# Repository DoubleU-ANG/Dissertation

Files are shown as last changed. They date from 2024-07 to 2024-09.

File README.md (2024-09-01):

# Dissertation: Connected Seat System
## Introduction: 
Smart Connected Seats serve as a helpful guide in public places like libraries and teaching theatres, assisting people in finding available and suitable seating. The Smart Connected Seats system combines a sensor-enabled chair and data communication centre. Every chair includes a millimetre-wave radar, to detect if someone is sitting down, along with sensors for carbon dioxide, temperature, humidity and light, to monitor the surrounding environment to ensure comfort. The communication centre visualises the data from the sensors. It includes model of the chairs, which rise when someone sits on real chairs, and an e-ink display to communicate the environmental conditions. 

## Hypothesis: 
How can a smart connected seat system using millimeter-wave radar and various environmental sensors help people to find a seat with better learning or working experience.

## Aims:
This project aims to implementing a smart Internet of Things (IoT) strategy on chairs, in order to transform the way we interact with these spaces

## Methodologies:
The Smart Connected System includes smart chair detector equipped with few sensors and physical twins of chair.

Project Overview:

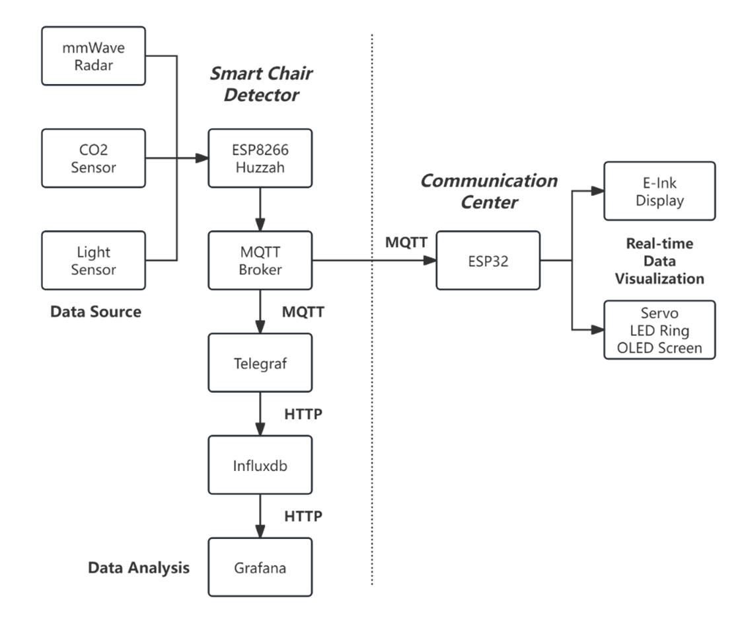
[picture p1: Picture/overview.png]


### Hardware:

#### Hardware List:

##### 1. Microcontrollers:
ESP8266 HUZZAH (Smart Chair Detector)
ESP32 E-paper screen driver board (Communication Center)

##### 2. Sensors:
This project use mm-Wave radar SEN0395, CO2, temperature and humidity sensor SCD30, and light sensor TCS3472. Use the code provided to test each sensor before integration.

SEN0395:

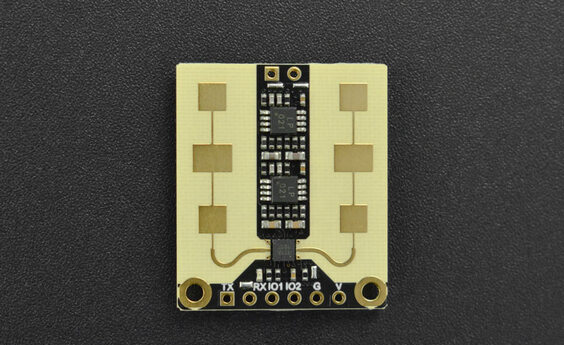
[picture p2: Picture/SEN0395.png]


SCD30:

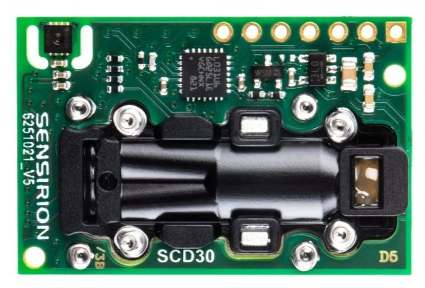
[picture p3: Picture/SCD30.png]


TCS3472:

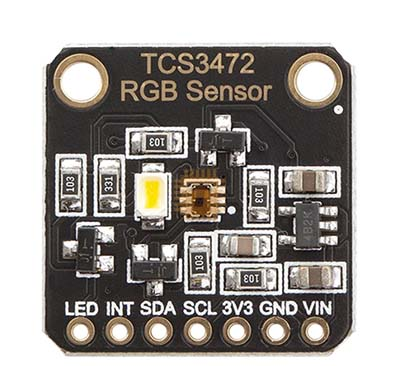
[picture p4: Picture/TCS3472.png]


##### 3. Actuators:
Actuators are mainly used in communication center, they are: servos, LED rings and OLED screens.

#### Circuit:
##### Circuit Connection:
Connect all the sensor as the schematic shown as below:

Smart chair detector circuit schematic:

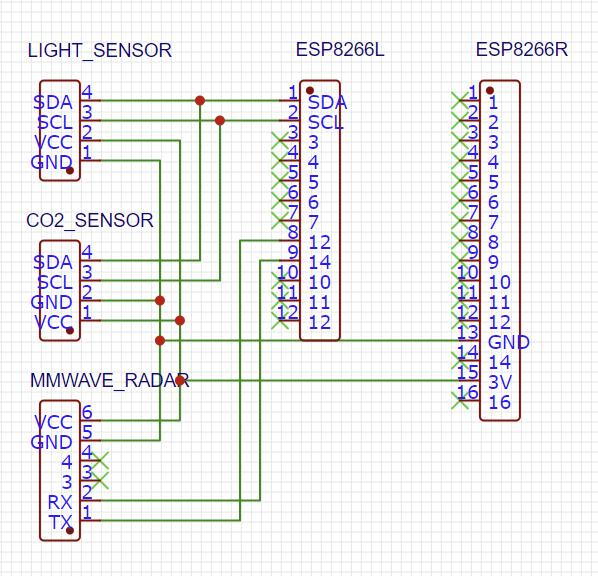
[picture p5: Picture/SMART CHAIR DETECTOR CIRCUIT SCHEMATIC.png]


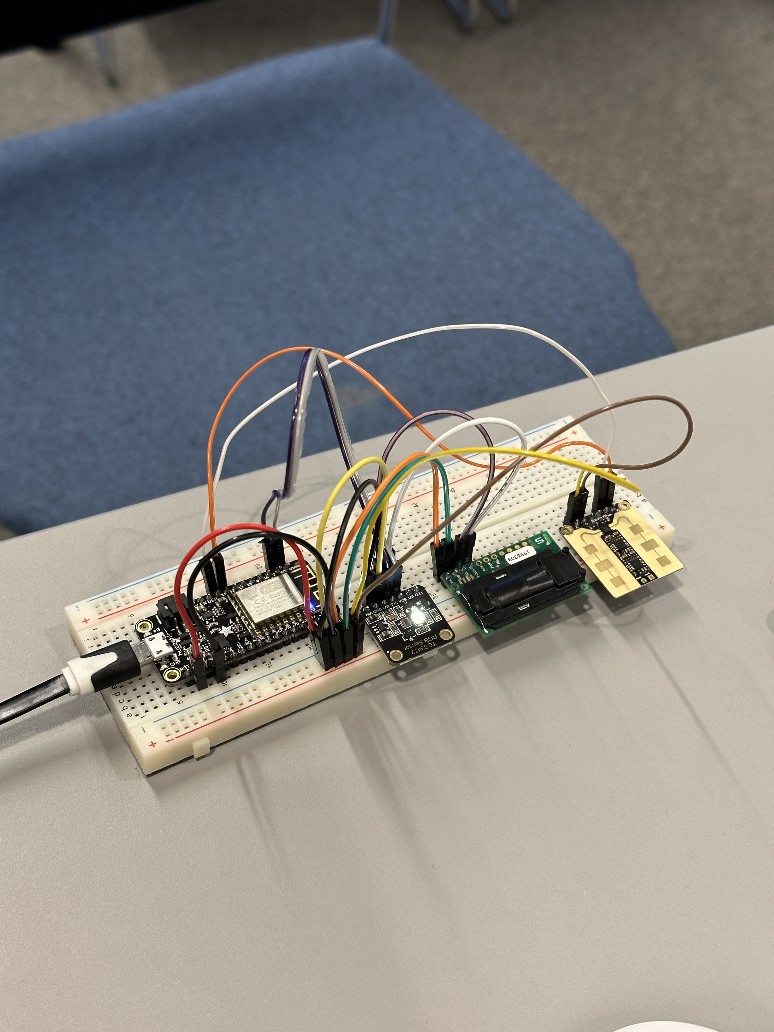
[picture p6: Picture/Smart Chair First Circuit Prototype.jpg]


Communication center circuit schematic:

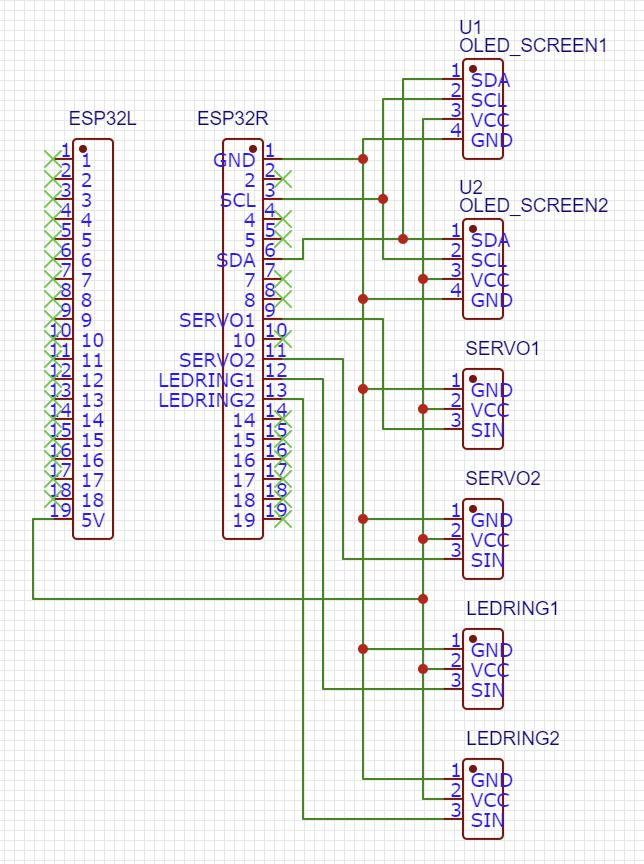
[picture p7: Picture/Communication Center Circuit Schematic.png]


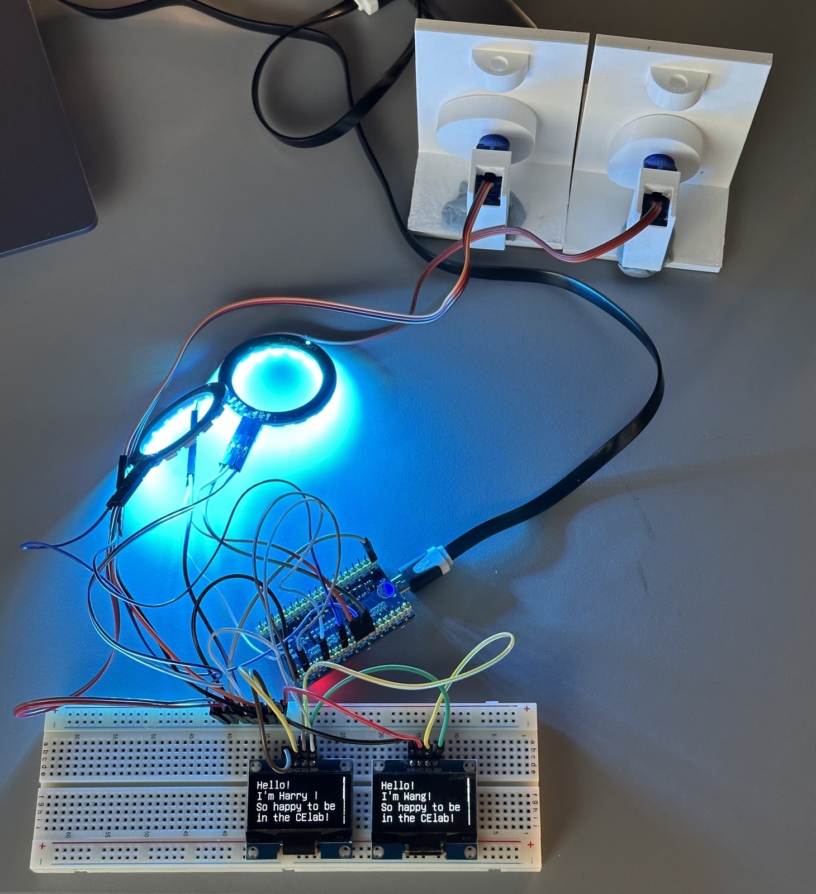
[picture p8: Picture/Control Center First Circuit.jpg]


It worth noting that when connect two OLED screens to circuit, physical address of one of them should be changed by soldering the resister behind the screen (shown as picture below) to another position for another address, otherwise the microcontroller is not able to recognise these two screens. It has two physical address； 0x78 and 0x7A，and 0x78 is the default one.

0x78；

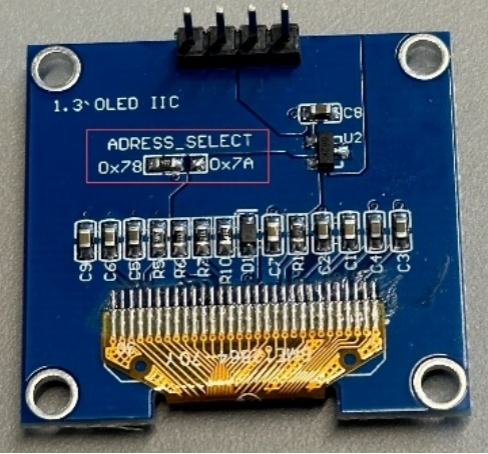
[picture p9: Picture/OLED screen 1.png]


0x7A:(manually modification needed)

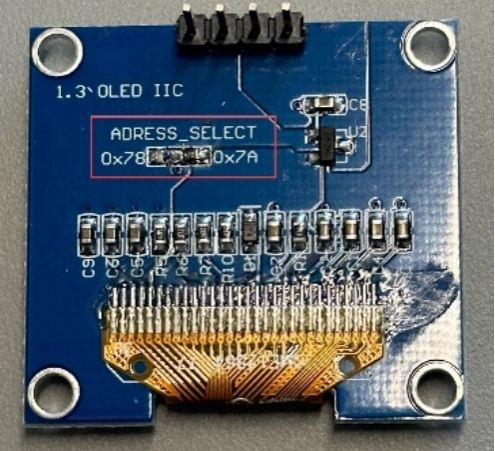
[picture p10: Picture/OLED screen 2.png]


After successfully assembling the circuit board and connecting all components, test the circuit functions in Arduino IDE by uploding the code provided to the microcontroller.

Code for smart chair detector:

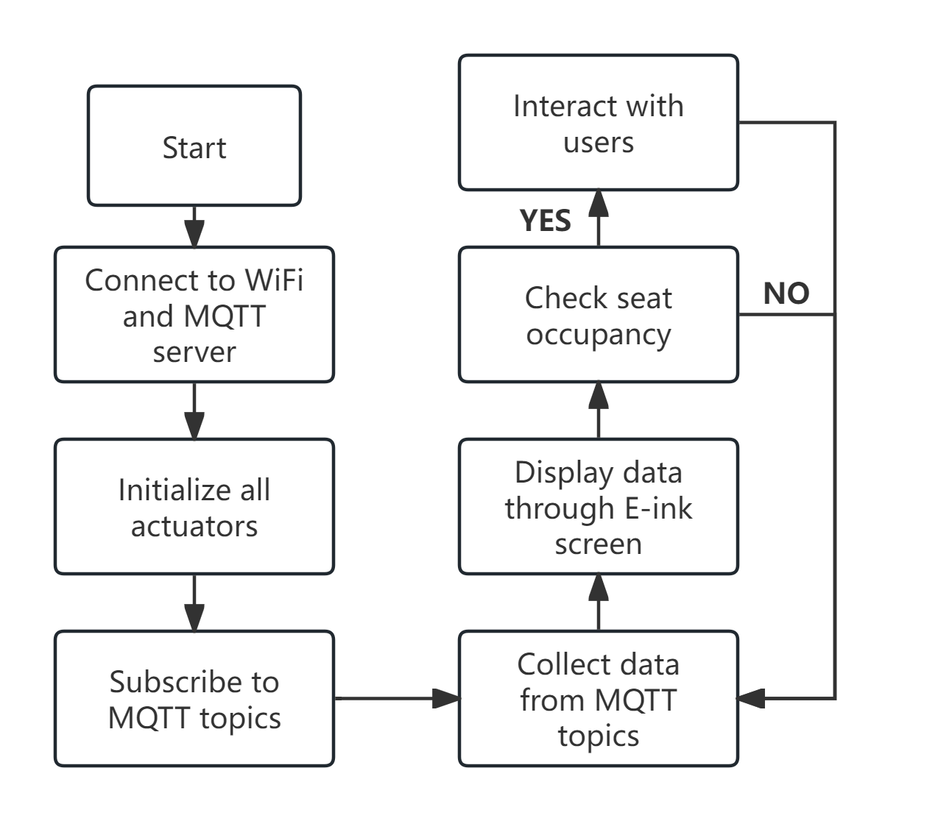
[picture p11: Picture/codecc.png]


Code for communication center:

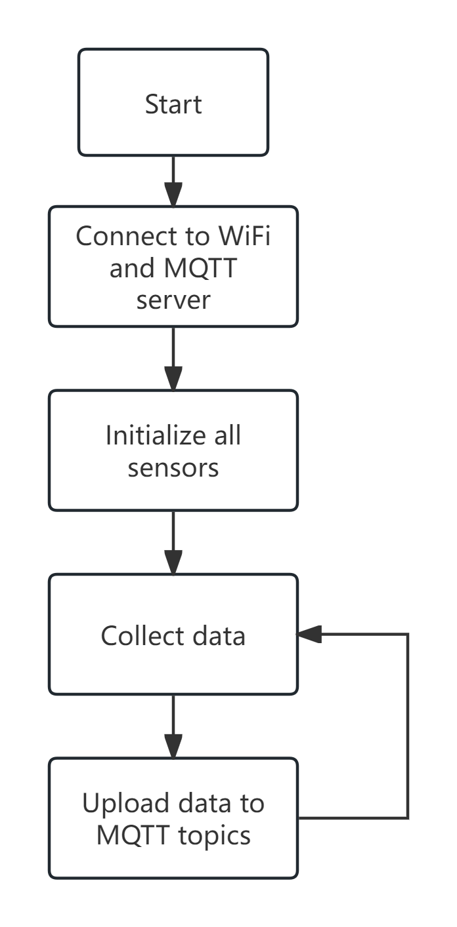
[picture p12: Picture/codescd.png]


##### Printed Circuit Board (PCB)
PCB has been designed for ensuring a more stable and wireless circuit. You can build your own PCB or modified mine which I designed on LCEDA according to your project.

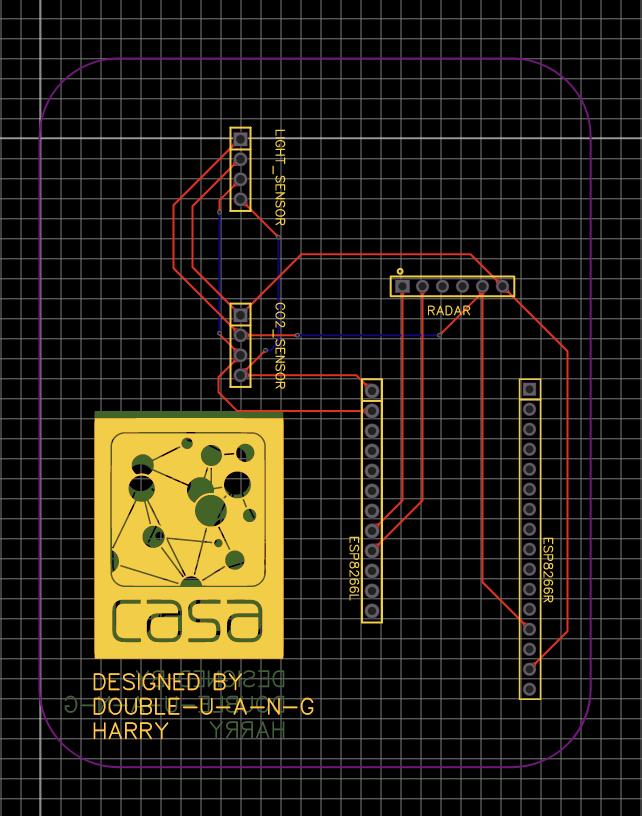
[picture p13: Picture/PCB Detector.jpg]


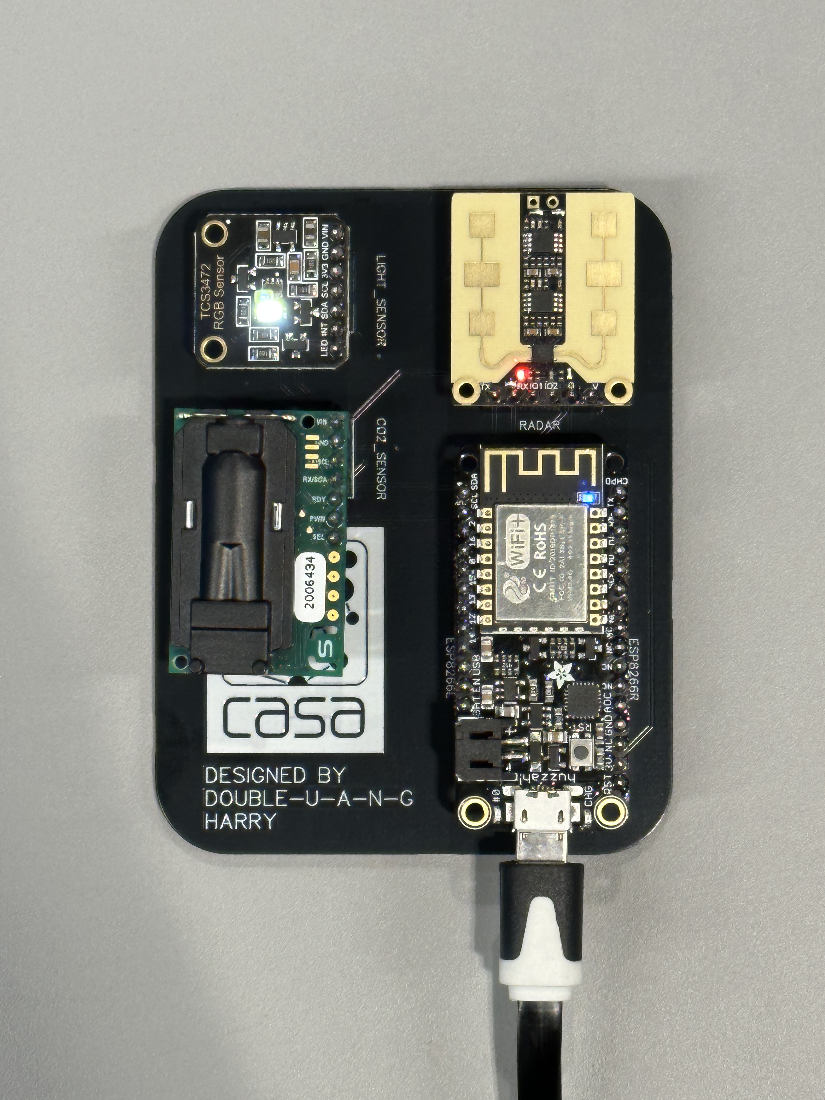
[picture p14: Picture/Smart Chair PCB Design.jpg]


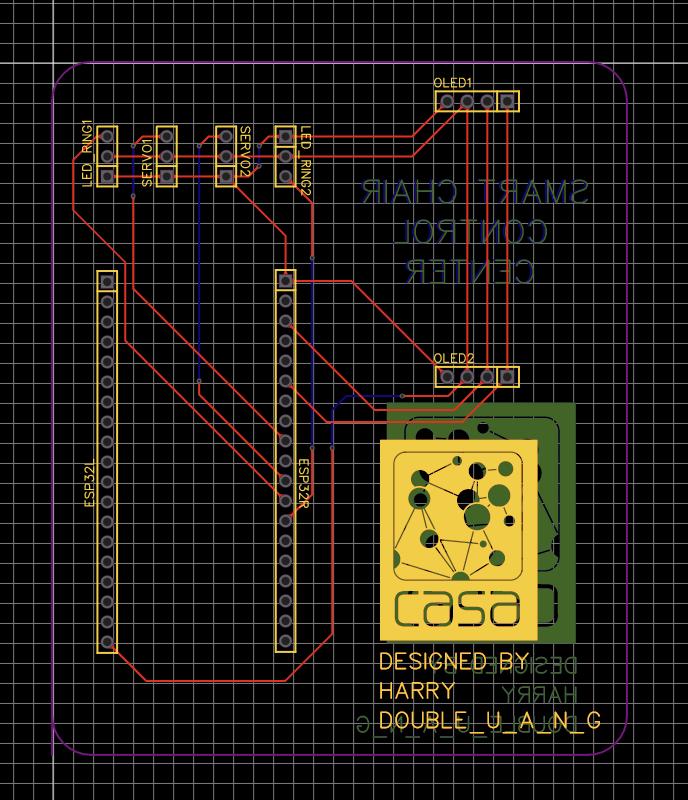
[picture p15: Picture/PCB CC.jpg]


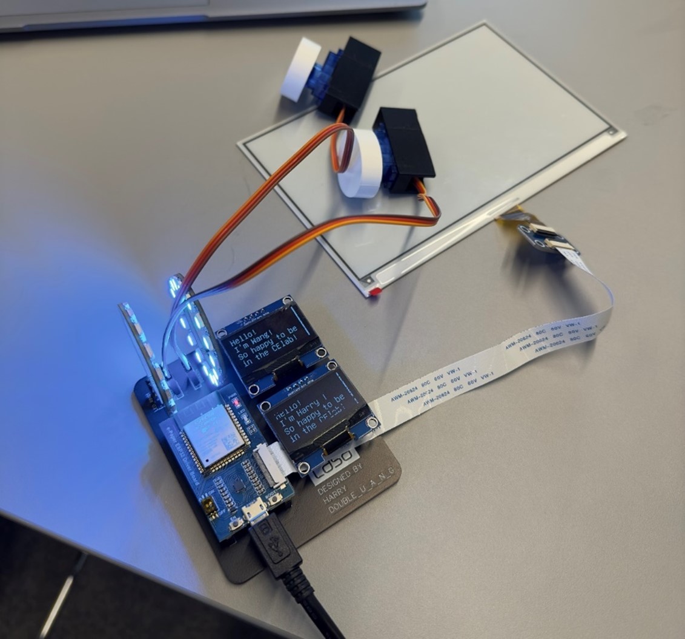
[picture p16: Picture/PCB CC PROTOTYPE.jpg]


#### Enclosure：
Custom-designed enclosures were developed for the circuit boards, sensors and actuators to facilitate their deployment in targeted scenarios. You can build your own enclosure or modified mine on Fusion 360 according to your project.

Smart Chair Detector Enclosure:

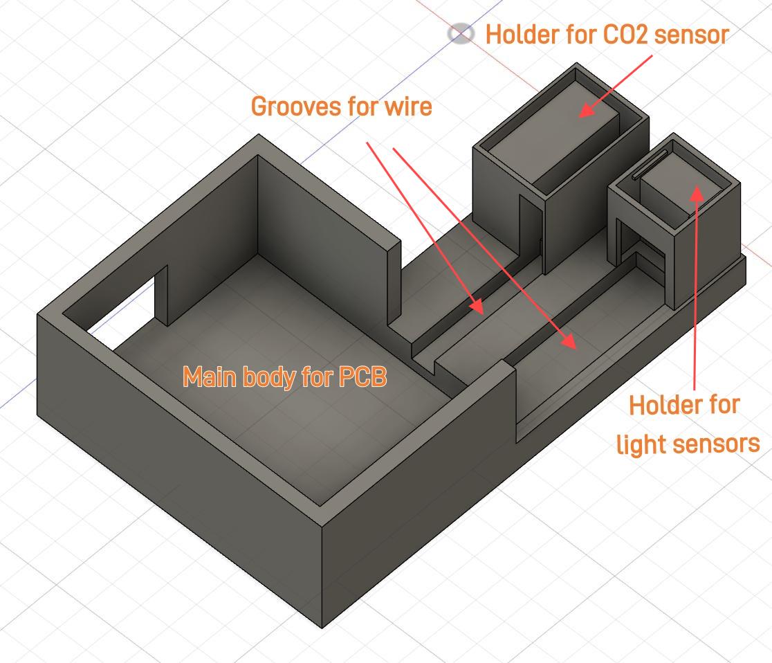
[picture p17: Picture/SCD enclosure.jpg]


Base of Communication Center:

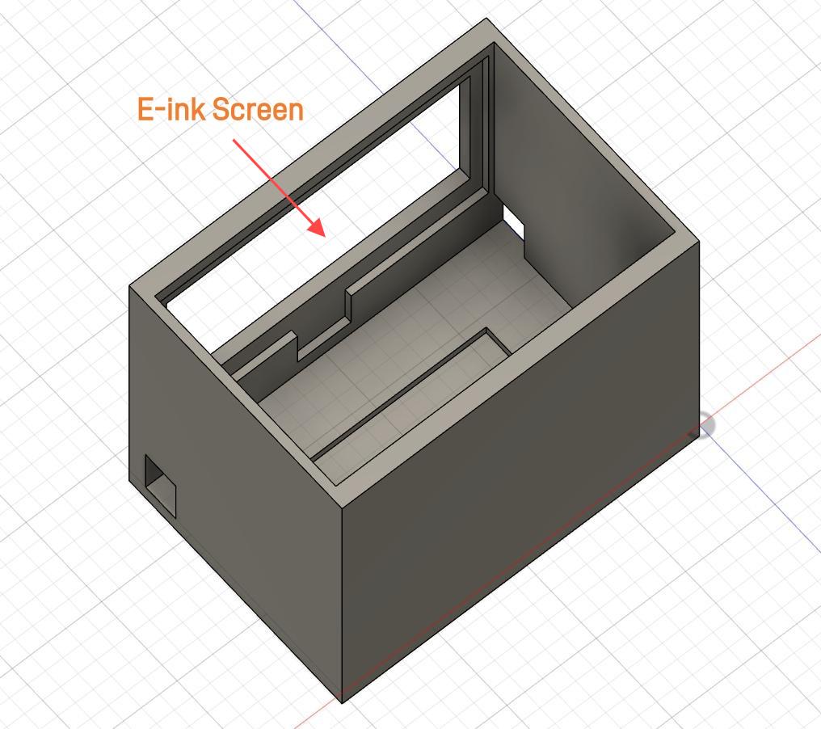
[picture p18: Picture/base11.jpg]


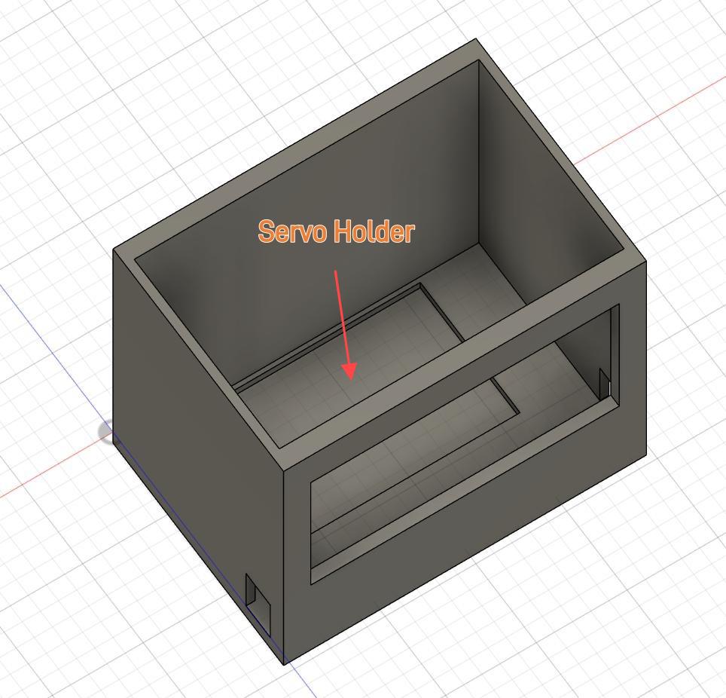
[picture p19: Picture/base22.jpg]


Servo Holder:

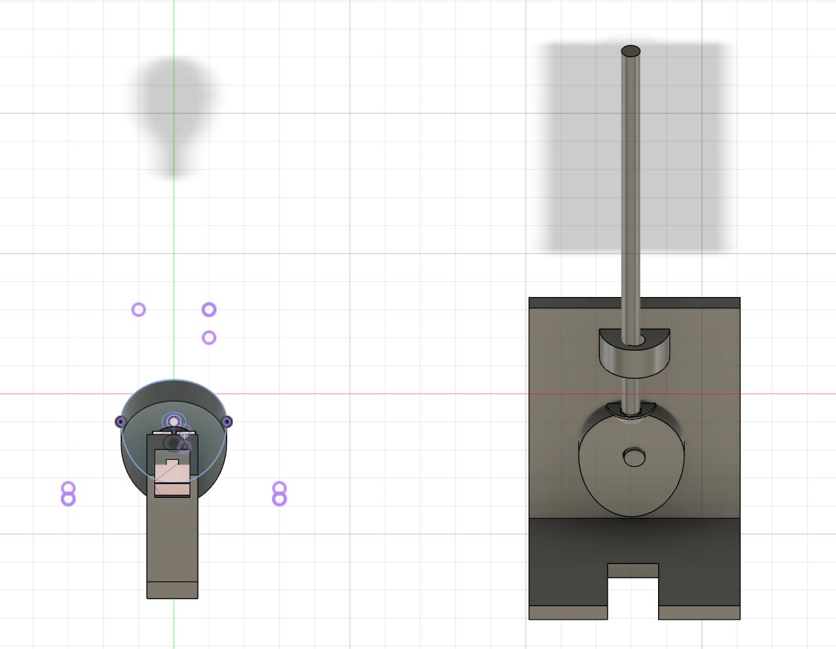
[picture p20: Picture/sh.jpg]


Top of Communication Center

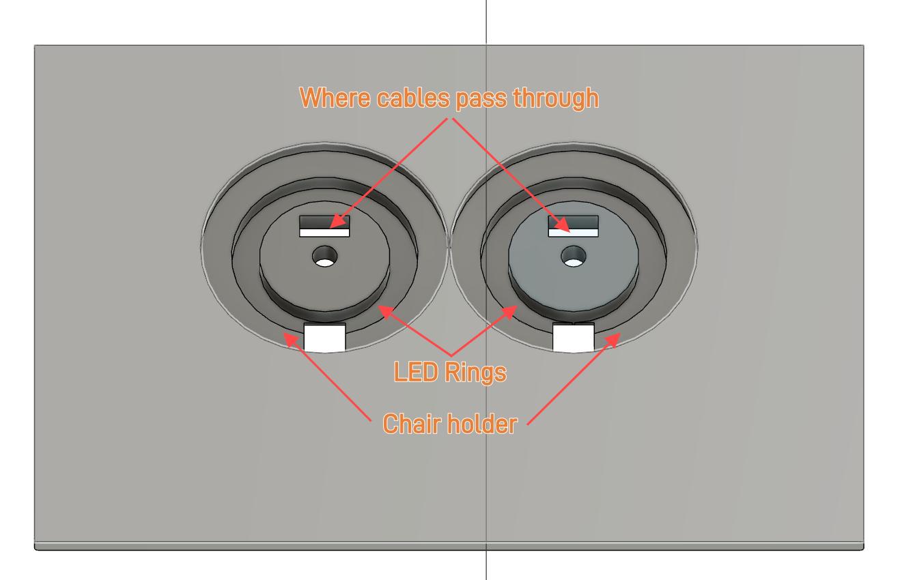
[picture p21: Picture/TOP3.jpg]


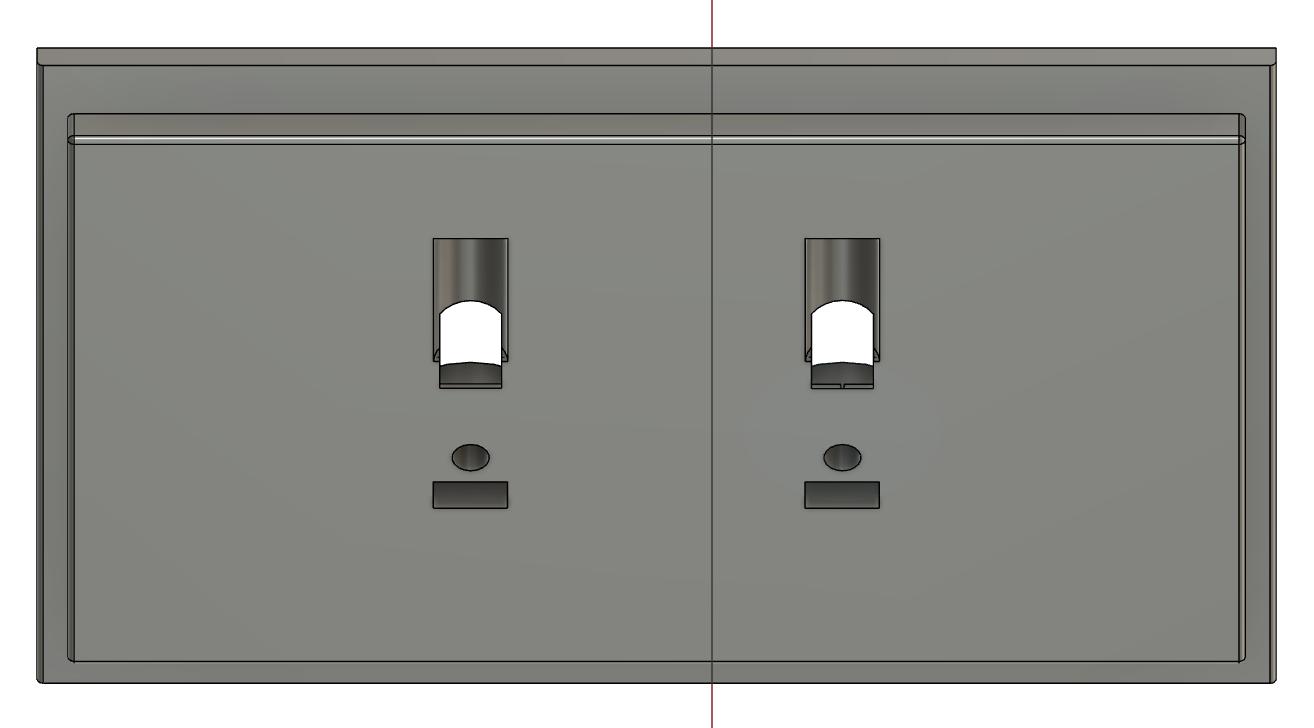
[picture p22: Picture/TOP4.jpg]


Chair Holder:

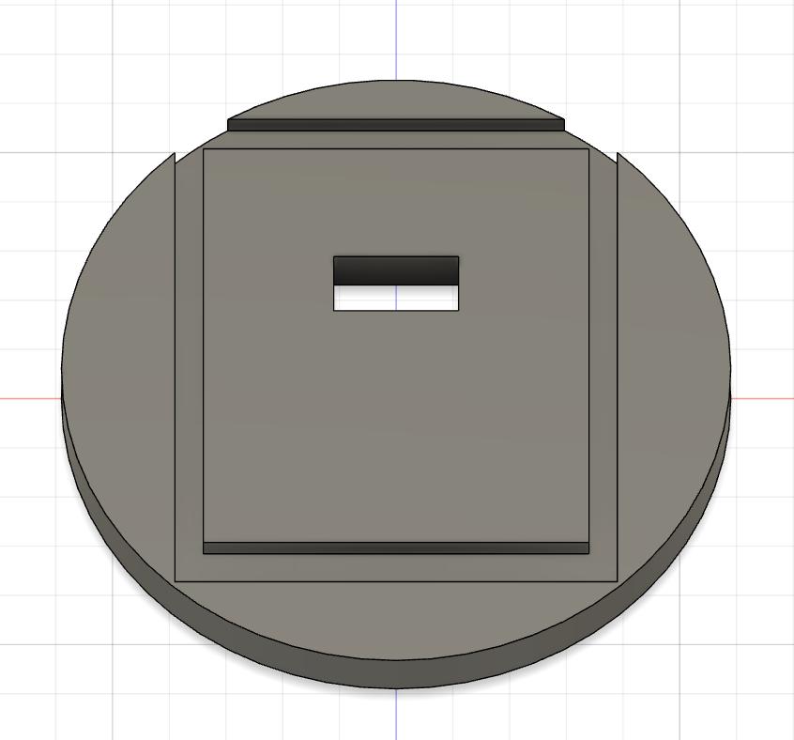
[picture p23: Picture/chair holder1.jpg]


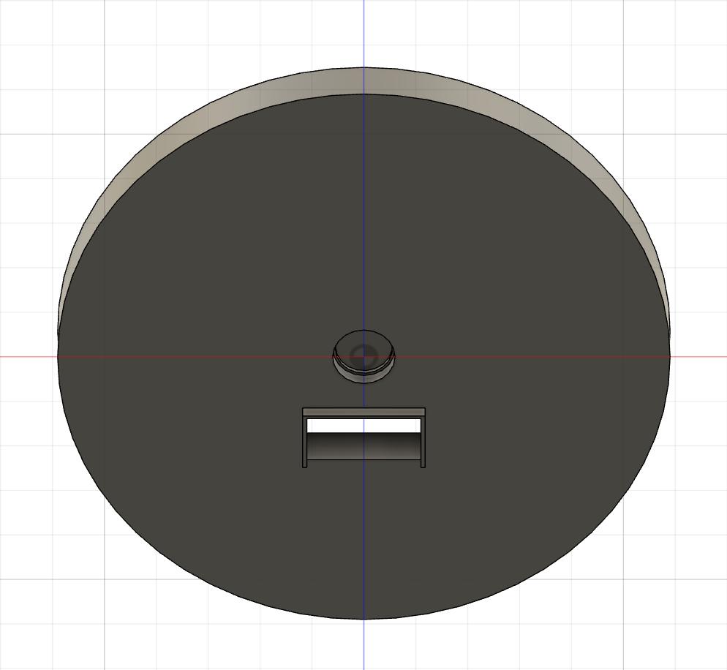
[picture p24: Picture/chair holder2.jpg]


Chair:

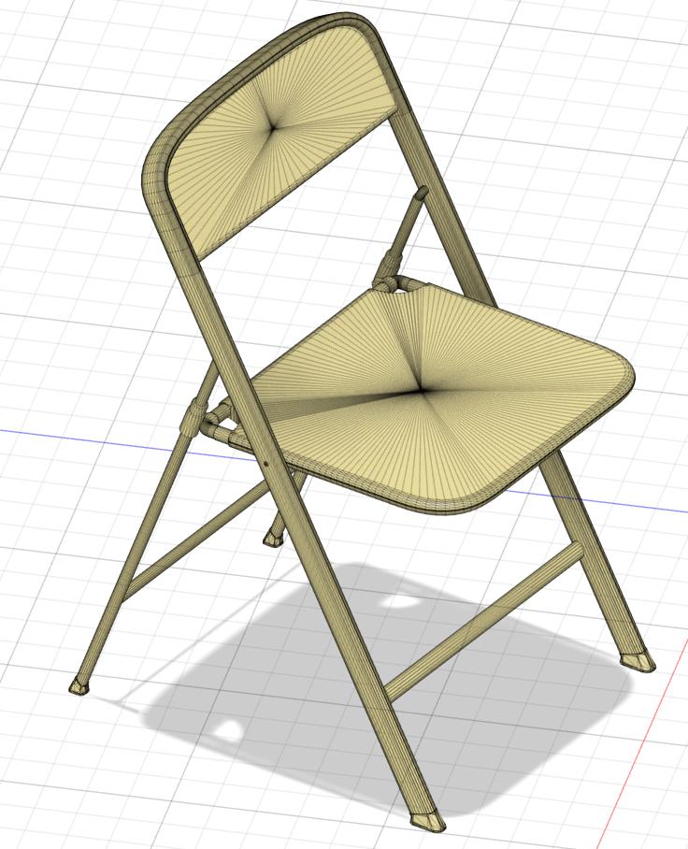
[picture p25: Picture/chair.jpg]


## Result:

Smart Chair Detector:

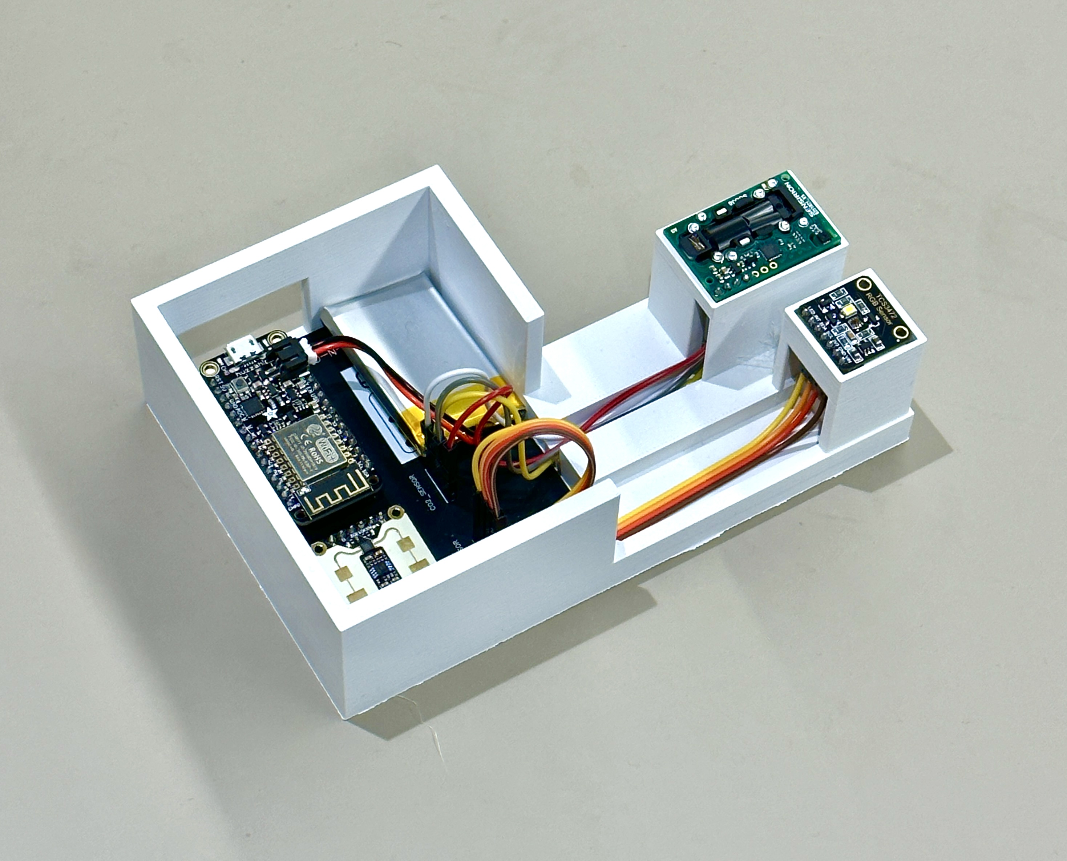
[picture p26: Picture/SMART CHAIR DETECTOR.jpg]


Deployment:

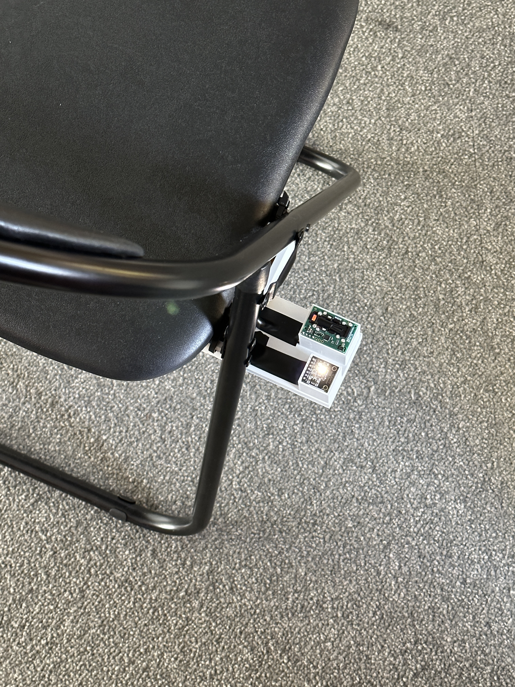
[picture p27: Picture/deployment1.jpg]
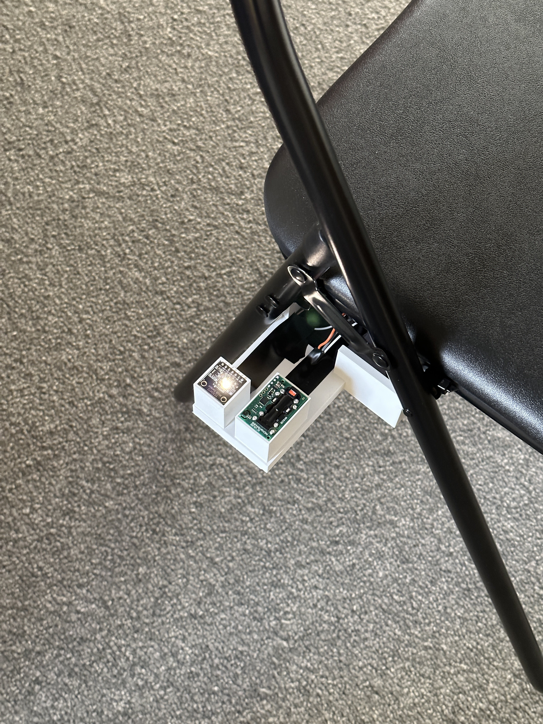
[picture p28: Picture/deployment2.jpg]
 

Communication Center:

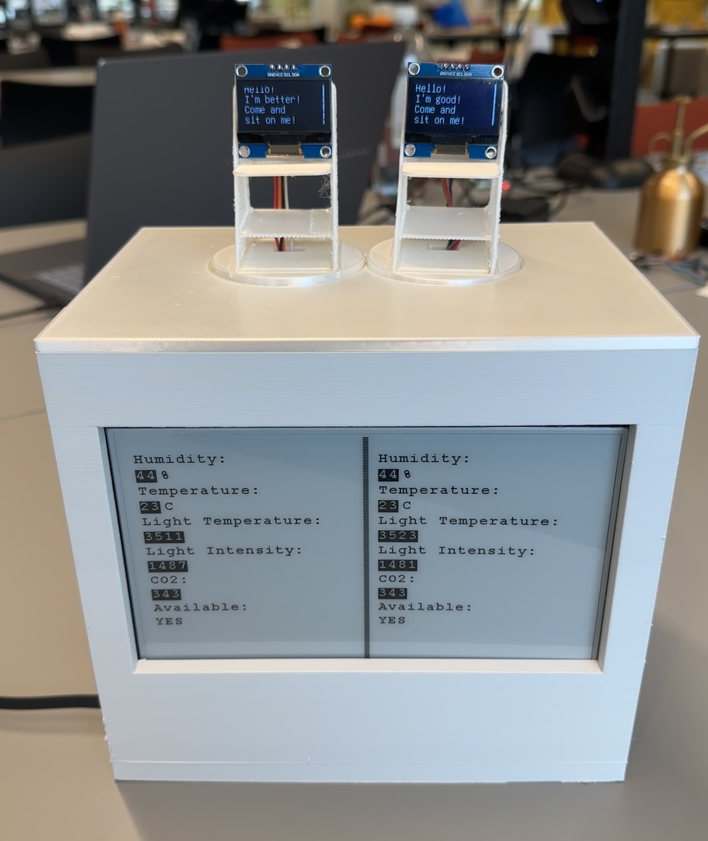
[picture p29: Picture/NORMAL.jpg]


When people sit on one of the chair:

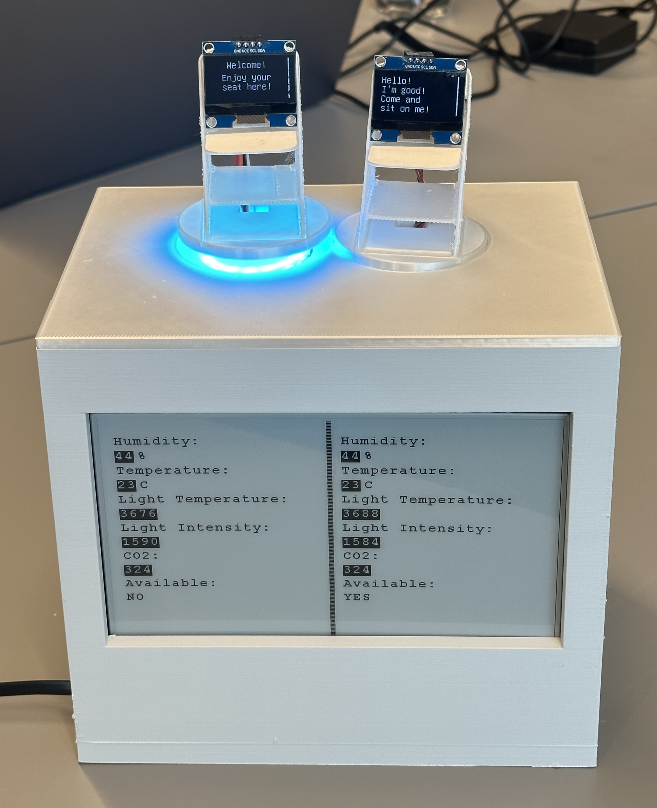
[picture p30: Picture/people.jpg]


## Steps for recreation:

1. Prepare the hardware needed.

2. Connect all the components and test the functions by code. Remember to replace the key information for WiFi and MQTT broker with your own one.

3. Design your PCB (optional) and Enclosure or modified mine according to your own requirement.

4. Assemble all the electronic components and enclosure.

5. Run the code and deploy on your chair

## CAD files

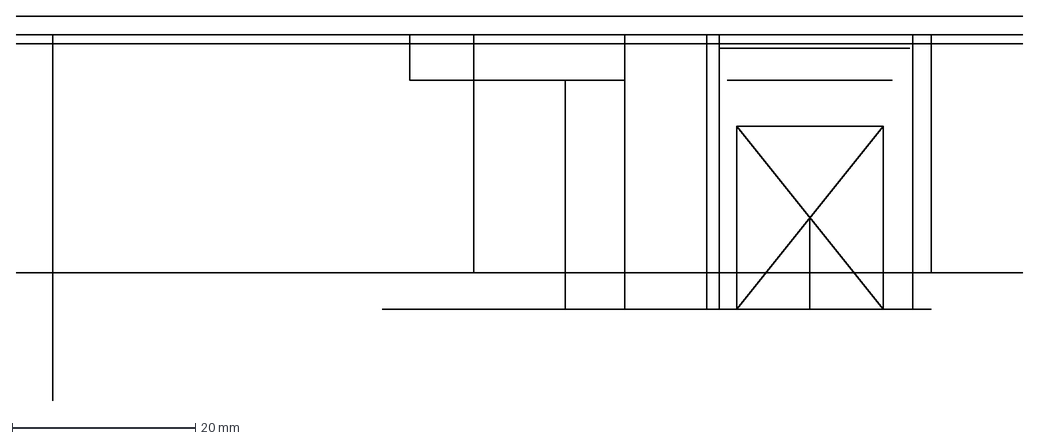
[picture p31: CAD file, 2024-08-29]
3D model/Smart Chair.dxf
110.0 x 42.0 mm

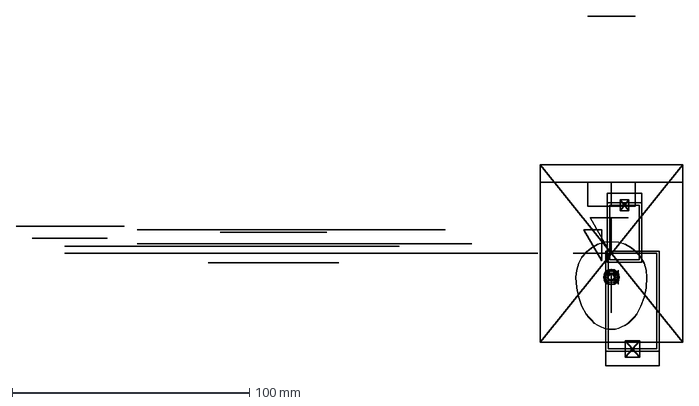
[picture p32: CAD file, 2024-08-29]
3D model/Control Center.dxf
281.0 x 147.3 mm

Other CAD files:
3D model/CHair.dxf

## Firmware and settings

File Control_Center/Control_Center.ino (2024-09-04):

#include "DEV_Config.h"
#include "EPD.h"
#include "GUI_Paint.h"
#include <PubSubClient.h>
#include <stdlib.h>
#include <WiFi.h>
#include <ezTime.h>
#include "SPIFFS.h"
#include <WiFi.h>
#include <HTTPClient.h>
#include <ArduinoJson.h>
#include <Adafruit_NeoPixel.h>
#include <ESP32Servo.h>
#include <Arduino.h>
#include <U8g2lib.h>
#include <Wire.h>
#ifdef __AVR__
#include <avr/power.h> // Required for 16 MHz Adafruit Trinket
#endif

#define PIN0 4 // On Trinket or Gemma, suggest changing this to 1
#define PIN1 16
// How many NeoPixels are attached to the Arduino?
#define NUMPIXELS 16 // Popular NeoPixel ring size
#define OLED_ADDR_1 0x3C
#define OLED_ADDR_2 0x3D
#define DELAYVAL 500 // Time (in milliseconds) to pause between pixels
// When setting up the NeoPixel library, we tell it how many pixels,
// and which pin to use to send signals. Note that for older NeoPixel
// strips you might need to change the third parameter -- see the
// strandtest example for more information on possible values.
Adafruit_NeoPixel pixels(NUMPIXELS, PIN0, NEO_GRB + NEO_KHZ800);
Adafruit_NeoPixel pixels1(NUMPIXELS, PIN1, NEO_GRB + NEO_KHZ800);
U8G2_SSD1306_128X64_NONAME_F_HW_I2C u8g2(U8G2_R0, /* reset=*/U8X8_PIN_NONE, /* clock=*/22, /* data=*/21);
U8G2_SSD1306_128X64_NONAME_F_HW_I2C u8g21(U8G2_R0, /* reset=*/U8X8_PIN_NONE, /* clock=*/22, /* data=*/21);
Servo myservo;
Servo myservo1;
int pos = 0;
int servoPin=18;
int servoPin1=17;

int light_temperature1 = 0;
int temperature1 = 0;
int humidity1 = 0;
int people1 = 0;
int light_intensity1 = 0;
int CO21 = 0;

int light_temperature2 = 0;
int temperature2 = 0;
int humidity2 = 0;
int people2 = 0;
int light_intensity2 = 0;
int CO22 = 0;

#define SECRET_SSID "use your own here"
#define SECRET_PASS "use your own here"
#define SECRET_MQTTUSER "use your own here"
#define SECRET_MQTTPASS "use your own here"

const char* ssid     = SECRET_SSID;
const char* password = SECRET_PASS;
const char* mqttuser = SECRET_MQTTUSER;
const char* mqttpass = SECRET_MQTTPASS;

const char* mqtt_server = "mqtt.cetools.org";
WiFiClient espClient;
PubSubClient client(espClient);
long lastMsg = 0;
char msg[50];
int value = 0;

UBYTE *BlackImage;
UWORD Imagesize = ((EPD_7IN5_V2_WIDTH % 8 == 0) ? (EPD_7IN5_V2_WIDTH / 8 ) : (EPD_7IN5_V2_WIDTH / 8 + 1)) * EPD_7IN5_V2_HEIGHT;

PAINT_TIME sys_time;
UWORD width = EPD_7IN5_V2_WIDTH;
UWORD height = EPD_7IN5_V2_HEIGHT;

UWORD line1_y = height / 3;
UWORD line2_y = height * 2 / 3;
UWORD line3_y = width / 2;

unsigned long lastUpdate = 0;  
const unsigned long updateInterval = 10000; 


void moveServoTo180(Servo &servo) {
  for (int pos = 0; pos <= 180; pos += 1) { 
    servo.write(pos);
    delay(20);
  }
}

// Function to move myservo from 180 to 0 degrees
void moveServoTo0(Servo &servo) {
  for (int pos = 180; pos >= 0; pos -= 1) {
    servo.write(pos);
    delay(20);
  }
}

void sentence01()
{
    u8g2.setFont(u8g2_font_unifont_t_chinese2); // use chinese2
 u8g2.firstPage();
 do
 {
  u8g2.setCursor(5, 15);
  u8g2.print("Hello!");
  u8g2.setCursor(5, 30);
  u8g2.print("I'm better!"); 
  u8g2.setCursor(5, 45);
  u8g2.print("Come and"); 
  u8g2.setCursor(5, 60); 
  u8g2.print("sit on me!"); 
 } while (u8g2.nextPage()); 
}

void sentence11()
{
   u8g21.setFont(u8g2_font_unifont_t_chinese2); // use chinese2
 u8g21.firstPage();
 do
 {
  u8g21.setCursor(5, 15);
  u8g21.print("Hello!");
  u8g21.setCursor(5, 30);
  u8g21.print("I'm good!"); 
  u8g21.setCursor(5, 45);
  u8g21.print("Come and"); 
  u8g21.setCursor(5, 60); 
  u8g21.print("sit on me!");
 } while (u8g21.nextPage()); 
}

void sentence02()
{
    u8g2.setFont(u8g2_font_unifont_t_chinese2); // use chinese2
 u8g2.firstPage();
 do
 {
  u8g2.setCursor(5, 15);
  u8g2.print("   Welcome!");
  u8g2.setCursor(5, 35);
  u8g2.print("  Enjoy your"); 
  u8g2.setCursor(5, 50);
  u8g2.print("  seat here!"); 
 // u8g2.setCursor(5, 60); 

 } while (u8g2.nextPage()); 
}

void sentence12()
{
   u8g21.setFont(u8g2_font_unifont_t_chinese2); // use chinese2
 u8g21.firstPage();
 do
 {
  u8g21.setCursor(5, 15);
  u8g21.print("Welcome!");
  u8g21.setCursor(5, 30);
  u8g21.print("Enjoy your"); 
  u8g21.setCursor(5, 45);
  u8g21.print("seat here!"); 
  u8g21.setCursor(5, 60); 
 
 } while (u8g21.nextPage()); 
}

void startWifi() {
  Serial.println();
  Serial.print("Connecting to ");
  Serial.println(ssid);
  WiFi.begin(ssid, password);

  while (WiFi.status() != WL_CONNECTED) {
    delay(500);
    Serial.print(".");
  }
  Serial.println("");
  Serial.println("WiFi connected");
  Serial.print("IP address: ");
  Serial.println(WiFi.localIP());
}

void sendMQTT() {
  if (!client.connected()) {
    reconnect();
  }
  client.loop();

  snprintf(msg, 50, "%.0i", t);
  Serial.print("Publish message for t: ");
  Serial.println(msg);
  client.publish("student/CASA0014/plant/ucfnaaf/rainrate1", msg);
}

void callback(char* topic, byte* payload, unsigned int length) {
  Serial.print("Message arrived [");
  Serial.print(topic);
  Serial.print("] ");

  char buffer[length + 1];
  for (int i = 0; i < length; i++) {
    buffer[i] = (char)payload[i];
    Serial.print(buffer[i]);
  }
  buffer[length] = '\0';
  Serial.println();

  if (strcmp(topic, "student/CASA0014/plant/ucfnaaf/Color Temperature1") == 0) {
    light_temperature = atoi(buffer);
    Serial.println("for the Color Temperature");
  } else if (strcmp(topic, "student/CASA0014/plant/ucfnaaf/Light Intensity1") == 0) {
    light_intensity = atoi(buffer);
    Serial.println("for the Light Intensity");
  } else if (strcmp(topic, "student/CASA0014/plant/ucfnaaf/Temperature1") == 0) {
    temperature = atoi(buffer);
    Serial.println("for the Temperature");
  } else if (strcmp(topic, "student/CASA0014/plant/ucfnaaf/Humidity1") == 0) {
    humidity = atoi(buffer);
    Serial.println("for the Humidity");
  } else if (strcmp(topic, "student/CASA0014/plant/ucfnaaf/CO21") == 0) {
    CO2 = atoi(buffer);
    Serial.println("for the CO2");
  } else if (strcmp(topic, "student/CASA0014/plant/ucfnaaf/People1") == 0) {
    people = atoi(buffer);
    Serial.println("for the People");
  }
    if (strcmp(topic, "student/CASA0014/plant/ucfnaaf/Color Temperature2") == 0) {
    light_temperature = atoi(buffer);
    Serial.println("for the Color Temperature");
  } else if (strcmp(topic, "student/CASA0014/plant/ucfnaaf/Light Intensity2") == 0) {
    light_intensity = atoi(buffer);
    Serial.println("for the Light Intensity");
  } else if (strcmp(topic, "student/CASA0014/plant/ucfnaaf/Temperature2") == 0) {
    temperature = atoi(buffer);
    Serial.println("for the Temperature");
  } else if (strcmp(topic, "student/CASA0014/plant/ucfnaaf/Humidity2") == 0) {
    humidity = atoi(buffer);
    Serial.println("for the Humidity");
  } else if (strcmp(topic, "student/CASA0014/plant/ucfnaaf/CO22") == 0) {
    CO2 = atoi(buffer);
    Serial.println("for the CO2");
  } else if (strcmp(topic, "student/CASA0014/plant/ucfnaaf/People2") == 0) {
    people = atoi(buffer);
    Serial.println("for the People");
  }
}

void reconnect() {
  while (!client.connected()) {
    Serial.print("Attempting MQTT connection...");
    String clientId = "ESP8266Client-";
    clientId += String(random(0xffff), HEX);
    
    if (client.connect(clientId.c_str(), mqttuser, mqttpass)) {
      Serial.println("connected");
      client.subscribe("student/CASA0014/plant/ucfnaaf/inTopic");
      client.subscribe("student/CASA0014/plant/ucfnaaf/Color Temperature1");
      client.subscribe("student/CASA0014/plant/ucfnaaf/Light Intensity1");
      client.subscribe("student/CASA0014/plant/ucfnaaf/Temperature1");
      client.subscribe("student/CASA0014/plant/ucfnaaf/Humidity1");
      client.subscribe("student/CASA0014/plant/ucfnaaf/CO21");
      client.subscribe("student/CASA0014/plant/ucfnaaf/Color Temperature2");
      client.subscribe("student/CASA0014/plant/ucfnaaf/Light Intensity2");
      client.subscribe("student/CASA0014/plant/ucfnaaf/Temperature2");
      client.subscribe("student/CASA0014/plant/ucfnaaf/Humidity2");
      client.subscribe("student/CASA0014/plant/ucfnaaf/CO22");
      client.subscribe("student/CASA0014/plant/ucfnaaf/People1");
      client.subscribe("student/CASA0014/plant/ucfnaaf/People2");
      
    } else {
      Serial.print("failed, rc=");
      Serial.print(client.state());
      Serial.println(" try again in 5 seconds");
      delay(5000);
    }
  }
}

void setup() {
  
  #if defined(__AVR_ATtiny85__) && (F_CPU == 16000000)
 clock_prescale_set(clock_div_1);
#endif
 pixels.begin(); // INITIALIZE NeoPixel strip object (REQUIRED)
 pixels1.begin();
 u8g2.setI2CAddress(OLED_ADDR_1 << 1); // I2C address needs to be left-shifted by 1
 u8g2.begin();
 u8g2.enableUTF8Print(); // enable UTF8 support for the Arduino print() function
 
 u8g21.setI2CAddress(OLED_ADDR_2 << 1); // I2C address needs to be left-shifted by 1
 u8g21.begin();
 u8g21.enableUTF8Print(); // enable UTF8 support for the Arduino print() function

 ESP32PWM::allocateTimer(0);
 ESP32PWM::allocateTimer(1);
 ESP32PWM::allocateTimer(2);
 ESP32PWM::allocateTimer(3);
 myservo.setPeriodHertz(50);
 myservo.attach(servoPin, 0, 2000); // attaches the servo on pin 18 to the servo object
 myservo1.setPeriodHertz(50);
 myservo1.attach(servoPin1, 0, 2000); // attaches the servo on pin 18 to the servo object
  myservo.write(0);
  myservo.write(1);
  Serial.begin(115200);
  startWifi();
  client.setServer(mqtt_server, 1884);
  client.setCallback(callback);

  delay(100);
  DEV_Module_Init();
  EPD_7IN5_V2_Init();
  EPD_7IN5_V2_Clear();
  DEV_Delay_ms(500);

  if ((BlackImage = (UBYTE *)malloc(Imagesize)) == NULL) {
    Serial.println("Failed to apply for black memory...");
    while (1);
  }

  Paint_NewImage(BlackImage, EPD_7IN5_V2_WIDTH, EPD_7IN5_V2_HEIGHT, 0, WHITE);
  Paint_Clear(WHITE); 
  Paint_DrawLine(line3_y, 0, line3_y, height, BLACK, DOT_PIXEL_5X5, LINE_STYLE_DOTTED);
  EPD_7IN5_V2_Display(BlackImage);
  delay(500);
   sentence01();
 delay(1000);
 sentence11();
 pixels.clear();
 pixels1.clear();
 pixels.show();
 pixels1.show();
 moveServoTo0(myservo);
 moveServoTo0(myservo1);
}

void loop() { 
  client.loop();
  sendMQTT();
  delay(1000);
  // 检查是否已经超过两分钟
  unsigned long currentMillis = millis();
  if (currentMillis - lastUpdate >= updateInterval) {
    lastUpdate = currentMillis;  // 记录这次更新的时间

    // 清空显示并绘制新内容
    Paint_Clear(WHITE); 
    Paint_DrawLine(line3_y, 0, line3_y, height, BLACK, DOT_PIXEL_5X5, LINE_STYLE_DOTTED);
      
    Paint_DrawString_EN(20, 30, "Humidity:", &Font24, WHITE, BLACK);
    Paint_DrawNum(20, 60, humidity1, &Font24, WHITE, BLACK);
    Paint_DrawString_EN(60, 60, "%", &Font24, WHITE, BLACK);
    Paint_DrawString_EN(20, 90, "Temperature:", &Font24, WHITE, BLACK);
    Paint_DrawNum(20, 120, temperature1, &Font24, WHITE, BLACK);
    Paint_DrawString_EN(60, 120, "C", &Font24, WHITE, BLACK);
    Paint_DrawString_EN(20, 150, "Light Temperature:", &Font24, WHITE, BLACK);
    Paint_DrawNum(20, 180, light_temperature1, &Font24, WHITE, BLACK);
    Paint_DrawString_EN(20, 210, "Light Intensity:", &Font24, WHITE, BLACK);
    Paint_DrawNum(20, 240, light_intensity1, &Font24, WHITE, BLACK);
    Paint_DrawString_EN(20, 270, "CO2:", &Font24, WHITE, BLACK);
    Paint_DrawNum(20, 300, CO21, &Font24, WHITE, BLACK);
    Paint_DrawString_EN(20, 330, "Available:", &Font24, WHITE, BLACK);
    
    if(people1 == 1) {
      Paint_DrawString_EN(20, 360, "YES", &Font24, WHITE, BLACK);  
      
      sentence01();
      pixels.clear();
    } else if(people1 == 2) {
      Paint_DrawString_EN(20, 360, "NO", &Font24, WHITE, BLACK);  
 pixels1.clear(); // Set all pixel colors to 'off'

 for(int i=0; i<NUMPIXELS; i++) { // For each pixel...

 pixels1.setPixelColor(i, pixels.Color(0, 150, 250));

 pixels1.show();
// Pause before next pass through loop
 
 }
          sentence02();
  myservo1.write(180);
    }

    Paint_DrawString_EN(line3_y + 20, 30, "Humidity:", &Font24, WHITE, BLACK);
    Paint_DrawNum(line3_y + 20, 60, humidity2, &Font24, WHITE, BLACK);
    Paint_DrawString_EN(line3_y + 60, 60, "%", &Font24, WHITE, BLACK);
    Paint_DrawString_EN(line3_y + 20, 90, "Temperature:", &Font24, WHITE, BLACK);
    Paint_DrawNum(line3_y + 20, 120, temperature2, &Font24, WHITE, BLACK);
    Paint_DrawString_EN(line3_y + 60, 120, "C", &Font24, WHITE, BLACK);
    Paint_DrawString_EN(line3_y + 20, 150, "Light Temperature:", &Font24, WHITE, BLACK);
    Paint_DrawNum(line3_y + 20, 180, light_temperature2, &Font24, WHITE, BLACK);
    Paint_DrawString_EN(line3_y + 20, 210, "Light Intensity:", &Font24, WHITE, BLACK);
    Paint_DrawNum(line3_y + 20, 240, light_intensity2, &Font24, WHITE, BLACK);
    Paint_DrawString_EN(line3_y + 20, 270, "CO2:", &Font24, WHITE, BLACK);
    Paint_DrawNum(line3_y + 20, 300, CO22, &Font24, WHITE, BLACK);
    Paint_DrawString_EN(line3_y + 20, 330, "Available:", &Font24, WHITE, BLACK);
    if(people2 == 1) {
      Paint_DrawString_EN(20, 360, "YES", &Font24, WHITE, BLACK);  
      
      sentence11();
      pixels.clear();
    } else if(people2 == 2) {
      Paint_DrawString_EN(20, 360, "NO", &Font24, WHITE, BLACK);  
 pixels.clear(); // Set all pixel colors to 'off'

 for(int i=0; i<NUMPIXELS; i++) { // For each pixel...

 pixels.setPixelColor(i, pixels.Color(0, 150, 250));

 pixels.show();
// Pause before next pass through loop
 
 }
          sentence12();
  myservo.write(180);
    } 

    
    EPD_7IN5_V2_Display(BlackImage);
  }
}

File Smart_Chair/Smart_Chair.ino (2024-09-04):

#include <ESP8266WiFi.h>
#include <PubSubClient.h>
#include <Wire.h>
#include <Adafruit_TCS34725.h>
#include <Adafruit_SCD30.h>
#include <SoftwareSerial.h>
#include <Ticker.h>
#include <DFRobot_mmWave_Radar.h>
int LED_BLINK = 2;

#define SECRET_SSID "use your own here"
#define SECRET_PASS "use your own here"
#define SECRET_MQTTUSER "use your own here"
#define SECRET_MQTTPASS "use your own here"

// Ticker timer;

const char* ssid     = SECRET_SSID;
const char* password = SECRET_PASS;
const char* mqttuser = SECRET_MQTTUSER;
const char* mqttpass = SECRET_MQTTPASS;

const char* mqtt_server = "mqtt.cetools.org";
WiFiClient espClient;
PubSubClient client(espClient);
long lastMsg = 0;
char msg[50];
float temp=0;
float Humi=0;
float CO=0;
int value = 0;
int people = 0;
int people1 = 0;
int people2=0;
int people3=0;
uint16_t r, g, b, c, colorTemp, lux;
int val=-1;

SoftwareSerial mySerial(12, 14);
DFRobot_mmWave_Radar sensor(&mySerial);
Adafruit_SCD30  scd30;
Adafruit_TCS34725 tcs = Adafruit_TCS34725(TCS34725_INTEGRATIONTIME_614MS, TCS34725_GAIN_1X);

// void onTimer() {
//   sensor.factoryReset();       
//   sensor.DetRangeCfg(0, 0.5);   
//   sensor.OutputLatency(0, 0); 
//     Serial.println("Timer triggered!");
// }

Ticker restartTimer;

void restartESP() {
    Serial.println("Restarting now...");
    ESP.restart();  
}

void setup() {

  // put your setup code here, to run once:
  Serial.begin(115200);
  restartTimer.attach(90, restartESP);
    sensor.factoryReset();       
  sensor.DetRangeCfg(0, 0.5);   
  sensor.OutputLatency(0, 0); 
  // timer.attach(90, onTimer);
  mySerial.begin(115200);
  startWifi();
  pinMode(BUILTIN_LED, OUTPUT);     
  digitalWrite(BUILTIN_LED, HIGH);  
  // start MQTT server
  client.setServer(mqtt_server, 1884);
  client.setCallback(callback);
  pinMode(LED_BLINK, OUTPUT);
 
  while (!Serial) delay(10);     // will pause Zero, Leonardo, etc until serial console opens

  Serial.println("Adafruit SCD30 test!");

  // Try to initialize!
  if (!scd30.begin()) {
    Serial.println("Failed to find SCD30 chip");
    while (1) { delay(10); }
  }
  Serial.println("SCD30 Found!");


  // if (!scd30.setMeasurementInterval(10)){
  //   Serial.println("Failed to set measurement interval");
  //   while(1){ delay(10);}
  // }
  Serial.print("Measurement Interval: "); 
  Serial.print(scd30.getMeasurementInterval()); 
  Serial.println(" seconds");
  
   if (tcs.begin()) {

  Serial.println("Found sensor");

 } else {

  Serial.println("No TCS34725 found ... check your connections");

  while (1);

 }
 
}

void loop() {

    people=0;
    people1=0;
    people2=0;
    people3=0;
    Serial.print(people);
  // put your main code here, to run repeatedly:
  if (scd30.dataReady()){
   // Serial.println("Data available!");

    if (!scd30.read()){ Serial.println("Error reading sensor data"); return; }

    Serial.print("Temperature: ");
    temp=scd30.temperature;
    Serial.print(temp);
    Serial.println(" degrees C");
    
    Serial.print("Relative Humidity: ");
    Humi=scd30.relative_humidity;
    Serial.print(Humi);
    Serial.println(" %");
    
    Serial.print("CO2: ");
    CO=scd30.CO2;
    Serial.print(scd30.CO2, 3);
    Serial.println(" ppm");
    Serial.println("");
  } else {
    //Serial.println("No data");
  }


 tcs.getRawData(&r, &g, &b, &c);

 // colorTemp = tcs.calculateColorTemperature(r, g, b);

 colorTemp = tcs.calculateColorTemperature_dn40(r, g, b, c);

 lux = tcs.calculateLux(r, g, b);

 Serial.print("Color Temp: "); Serial.print(colorTemp, DEC); Serial.print(" K - ");

 Serial.print("Lux: "); Serial.print(lux, DEC); Serial.print(" - ");

 Serial.print("R: "); Serial.print(r, DEC); Serial.print(" ");

 Serial.print("G: "); Serial.print(g, DEC); Serial.print(" ");

 Serial.print("B: "); Serial.print(b, DEC); Serial.print(" ");

 Serial.print("C: "); Serial.print(c, DEC); Serial.print(" ");

 Serial.println(" ");

  val = sensor.readPresenceDetection();
  if(val==1)
  {

        Serial.println("People:Yes");
        people=2;
        people1=20;
        people2=200;
        people3=2000;

  }
  else if(val==0)
  {
    Serial.println("People:No");
    people=1;
    people1=10;
    people2=100;
    people3=1000;
  }
  else
  {
    Serial.println("Error");
  }
  delay(1000);

    sendMQTT();
  client.loop();
}

void startWifi() {
  // We start by connecting to a WiFi network
  Serial.println();
  Serial.print("Connecting to ");
  Serial.println(ssid);
  WiFi.begin(ssid, password);

  // check to see if connected and wait until you are
  while (WiFi.status() != WL_CONNECTED) {
    delay(500);
    Serial.print(".");
  }
  Serial.println("");
  Serial.println("WiFi connected");
  Serial.print("IP address: ");
  Serial.println(WiFi.localIP());
}

void sendMQTT() { //send to different topic for different seat

  if (!client.connected()) {
    reconnect();
  }
  client.loop();


  snprintf (msg, 50, "%.0i", colorTemp);
  // Serial.print("Publish message for t: ");
  // Serial.println(msg);
  client.publish("student/CASA0014/plant/ucfnaaf/Color Temperature", msg);


  snprintf (msg, 50, "%.0i", lux);
  // Serial.print("Publish message for h: ");
  // Serial.println(msg);
  client.publish("student/CASA0014/plant/ucfnaaf/Light Intensity", msg);

  //Moisture = analogRead(soilPin);   // moisture read by readMoisture function
  snprintf (msg, 50, "%.0i", people);
  // Serial.print("Publish message for m: ");
  // Serial.println(msg);
  client.publish("student/CASA0014/plant/ucfnaaf/People", msg);

  snprintf (msg, 50, "%.0i", people1);
  // Serial.print("Publish message for m: ");
  // Serial.println(msg);
  client.publish("student/CASA0014/plant/ucfnaaf/People1", msg);

  snprintf (msg, 50, "%.0i", people2);
  // Serial.print("Publish message for m: ");
  // Serial.println(msg);
  client.publish("student/CASA0014/plant/ucfnaaf/People2", msg);

  snprintf (msg, 50, "%.0i", people3);
  // Serial.print("Publish message for m: ");
  // Serial.println(msg);
  client.publish("student/CASA0014/plant/ucfnaaf/People3", msg);

  snprintf (msg, 50, "%.2f", temp);
  // Serial.print("Publish message for m: ");
  // Serial.println(msg);
  client.publish("student/CASA0014/plant/ucfnaaf/Temperature", msg);  

  snprintf (msg, 50, "%.2f", Humi);
  // Serial.print("Publish message for m: ");
  // Serial.println(msg);
  client.publish("student/CASA0014/plant/ucfnaaf/Humidity", msg);

  snprintf (msg, 50, "%.2f", CO);
  // Serial.print("Publish message for m: ");
  // Serial.println(msg);
  client.publish("student/CASA0014/plant/ucfnaaf/CO2", msg);
}
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
